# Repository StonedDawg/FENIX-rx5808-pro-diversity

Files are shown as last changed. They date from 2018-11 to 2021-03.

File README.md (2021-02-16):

https://discord.gg/gG2sjjK

Diversity receiver designed around an ESP32 and touchpad UI.

  *   15 kHz antenna switching rate e.g. once every NTSC video line.
  *   72 selectable frequencies
  *   Rapid spectrum analyser with selectable peaks.  See below for more details.
  *   Switch from diversity mode, to single antenna mode (A or B).

Menu demo (36 seconds) https://www.youtube.com/watch?v=VTEIN2PMyIs

Indoor flight (29 seconds) https://www.youtube.com/watch?v=gvrL2I_6KYo



**Calibration**

When first built and turned on you will be greeted with a calibration screen.  Set a VTx to 25 mW and on your favourite band/frequency (F4 for 5800 MHz) and place the VTx next to the goggles.  Tap the touchpad and the module will sweep all frequencies tracking maximum and minimum RSSI values.  When completed you will see the final min/max values for each receiver and can tapping again saves these values.
press any button to step the process.
The calibration process can be enhanced by selecting "enhance calibration" from menu or reset by selecting "factory reset" from internal settings menu.

**Diversity or single antenna selection**

Tapping on mode cycles through diversity, antenna A, and antenna B modes.

**button navigation**

use fatshark up/down CH as the button. changing value (going up or going down) will cycle
menu. to simulate enter button, change the direction, for example, after cycling with up button, to select the item, press the down button.

**note : due to fatshark "garbage" button system as Jye said, when button up or down has been pressed too many time (fatshark will do longer beep when pressed), menu cycling will stop. to keep cycling the menu, go with the opposite direction, it will not simulate enter button from a max-ed value button.

## BOM

  *   1 x PCB - Upload the Gerber.zip found in the PCB folder to jlcpcb.com, select 1mm thickness and your favourite colour. https://easyeda.com/jyesmith/esp32-fatshark-module-v3
  *   1 x GlidePoint circle pads Part Number (SPI) TM023023-2024-002
     *   https://www.cirque.com/glidepoint-circle-trackpads
     *   https://au.mouser.com/ProductDetail/Cirque/TM023023-2024-002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
  *   1 x TTGO Micro-32
     *   https://www.aliexpress.com/item/Ttgo-Micro-32-V2-0-Wifi-Wireless-Bluetooth-Module-Esp32-Pico-D4-Ipex-Esp-32/32982085061.html
  *   2 x RX5808.  The receiver linked below has given better results than the more commonly available receiver (the version without the 2 extra tabs).  The RSSI voltage range is  larger and the minimum RSSI is consistent across all frequencies.
     *   https://www.aliexpress.com/item/Swiftflying-Boscam-FPV-5-8G-Wireless-Audio-Video-Receiving-Module-For-RX5808/32841092602.html
  *   2 x Antenna Connectors
     *   https://www.aliexpress.com/item/5-pcs-RF-Coaxial-Long-SMA-Female-Straight-Edge-15mm-tooth-PCB-Connector-Adapter/32913905715.html
  *   3 x  Switch CD4065
  *   3.3V Regulator AMS1117-3.3
  *   2 x 10uF 0603 SMD Capacitors
  *   1 x 0.1uF 0603 SMD Capacitor
  *   1 x 10k 0603 SMD Resistors (EN pullup)
  *   2 x 100k 0603 SMD Resistors (RSSI pulldown)
  *   3 x 510 ohm 0603 SMD Resistors (LEDs) (Optional)
  *   3 x 0603 LEDs.  1 (red) for power and 2 (green) for indicating which antenna is selected (Optional)
  *   1 x boot button
  *   1 x 9 pin header
  *   2 x 4mm M2 standoffs and screws

# Wiring

https://easyeda.com/jyesmith/esp32-fatshark-module-v3

 

The touchpad works better with a cover.  I use a piece of electric tape.

 

 

 



## Flashing
initial flashing :
Tx and Rx pins to the TTGO are broken out to the upper 2 pins that plug into the goggles.  Connect these, along with GND (pin 3rd from bottom) and 5V (bottom pin), then flash using your favourite FTDI.

next update flashing can use OTA.

## Recognition

This code is a forked from [sheaivey/rx5808-pro-diversity](https://github.com/sheaivey/rx5808-pro-diversity).

## Code

The code is distributed under the [MIT license](LICENSE.md).

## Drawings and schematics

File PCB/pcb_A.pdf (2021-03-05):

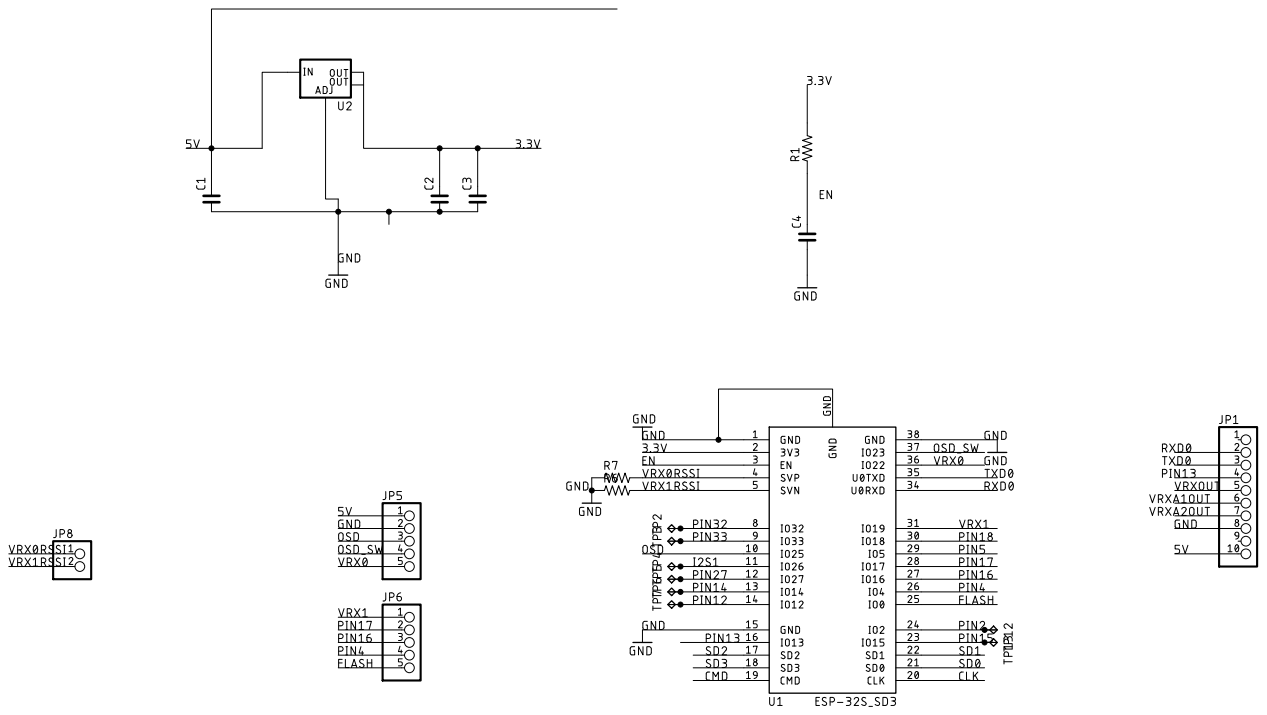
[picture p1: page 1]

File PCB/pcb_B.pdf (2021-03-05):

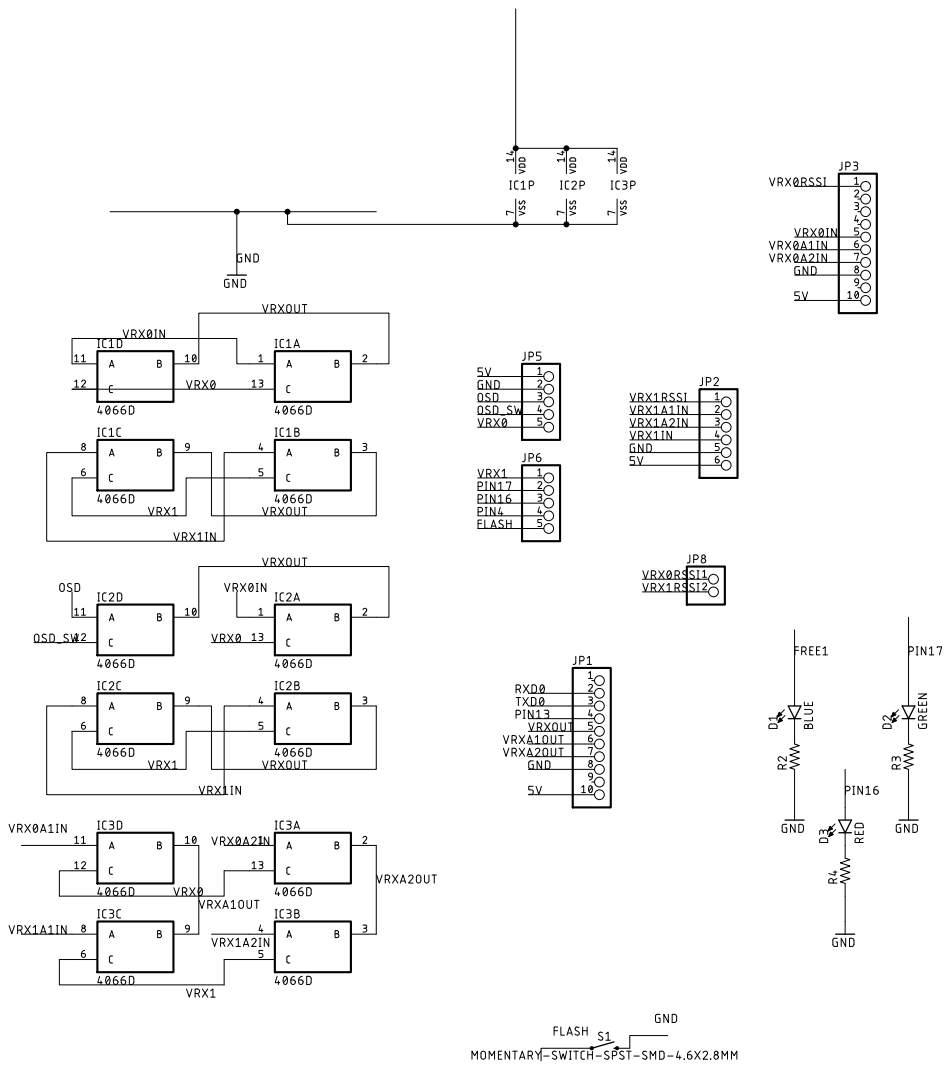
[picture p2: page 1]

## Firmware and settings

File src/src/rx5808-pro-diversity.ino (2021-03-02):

/*
   SPI driver based on fs_skyrf_58g-main.c Written by Simon Chambers
   TVOUT by Myles Metzel
   Scanner by Johan Hermen
   Inital 2 Button version by Peter (pete1990)
   Refactored and GUI reworked by Marko Hoepken
   Universal version my Marko Hoepken
   Diversity Receiver Mode and GUI improvements by Shea Ivey
   OLED Version by Shea Ivey
   Seperating display concerns by Shea Ivey

  The MIT License (MIT)

  Copyright (c) 2015 Marko Hoepken

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
  THE SOFTWARE IS PROVIDED "AS IS", WITHOUT WARRANTY OF ANY KIND, EXPRESS OR
  IMPLIED, INCLUDING BUT NOT LIMITED TO THE WARRANTIES OF MERCHANTABILITY,
  FITNESS FOR A PARTICULAR PURPOSE AND NONINFRINGEMENT. IN NO EVENT SHALL THE
  AUTHORS OR COPYRIGHT HOLDERS BE LIABLE FOR ANY CLAIM, DAMAGES OR OTHER
  LIABILITY, WHETHER IN AN ACTION OF CONTRACT, TORT OR OTHERWISE, ARISING FROM,
  OUT OF OR IN CONNECTION WITH THE SOFTWARE OR THE USE OR OTHER DEALINGS IN THE
  SOFTWARE.
*/

#include <EEPROM.h>
#include "esp_pm.h"
#include "settings.h"
#include "settings_eeprom.h"
#include "state_home.h"
#include "channels.h"
#include "receiver.h"
//#include "receiver_spi.h"
#include "state.h"
#include "ui.h"
#include "voltage.h"
#include "temperature.h"
//#include "touchpad.h"
//#include "receiver_spi.h"
#include <esp_now.h>
#include <WiFi.h>
#include "ExpressLRS_Protocol.h"
#include "WebUpdater.h"
#include "fsbutton.h"
#include "statusled.h"

#ifdef SPEED_TEST
    uint32_t n = 0; 
    uint32_t previousTime = millis();
#endif

fsBtn fatBtn;

//vrxDock vrxMdl;


/* 
    esp-now setup for communicating to https://github.com/AlessandroAU/ExpressLRS
    broadcastAddress is the mac of your receiving esp8266
*/


void floatUnusedPins(void);
uint8_t broadcastAddress[] = {0x50, 0x02, 0x91, 0xDA, 0x56, 0xCA,   // esp32 tx 50:02:91:DA:56:CA
                              0x50, 0x02, 0x91, 0xDA, 0x37, 0x84};  // r9 tx    50:02:91:DA:37:84
                              
bool updatingOTA = false;
uint32_t previousLEDTime = 0;
/**
vrxDockBtn vrxBtn0;
vrxDockBtn vrxBtn1;
vrxDockBtn vrxBtn2;
*/

void setup()
{
    rtc_clk_cpu_freq_set(RTC_CPU_FREQ_240M);
    esp_pm_lock_handle_t powerManagementLock;
    esp_pm_lock_create(ESP_PM_CPU_FREQ_MAX, 0, "compositeCorePerformanceLock", &powerManagementLock);
    esp_pm_lock_acquire(powerManagementLock);  
/**
vrxBtn0.residedAct = 0;
vrxBtn0.pressed = 0;
vrxBtn0.pin = PIN_BUTTON0;
vrxBtn0.lastReading = 0;
vrxBtn0.lastDebounceTime = 0;
vrxBtn0.changedTime = 0;
vrxBtn0.action0 = decrementVrxMode;
vrxBtn0.action1 = noActionBtn;
vrxBtn0.action2 = noActionBtn;

vrxBtn1.residedAct = 0;
vrxBtn1.pressed = 0;
vrxBtn1.pin = PIN_BUTTON1;
vrxBtn1.lastReading = 0;
vrxBtn1.lastDebounceTime = 0;
vrxBtn1.changedTime = 0;
vrxBtn1.action0 = noActionBtn;
vrxBtn1.action1 = noActionBtn;
vrxBtn1.action2 = enterOTA;

vrxBtn2.residedAct = 0;
vrxBtn2.pressed = 0;
vrxBtn2.pin = PIN_BUTTON2;
vrxBtn2.lastReading = 0;
vrxBtn2.lastDebounceTime = 0;
vrxBtn2.changedTime = 0;
vrxBtn2.action0 = incrementVrxMode;
vrxBtn2.action1 = noActionBtn;
vrxBtn2.action2 = noActionBtn;
*/


    //#ifdef SPEED_TEST
        //Serial.begin(115200);
    //#endif

    ////Serial.println("Setting Up..");
    EEPROM.begin(2048);
    
    ////Serial.println("EEPROM begin DONE");
    //SPI.begin();
    EepromSettings.setup();
    floatUnusedPins();
    statusLedInit();
    fsBtnInit();
    Receiver::setup(); 
    
    ////Serial.println("EEPROM set");
    
    
    
    ////Serial.println("pin set");
    StateMachine::setup();
    
    ////Serial.println("Statemachine set");
    Ui::setup(); 
    
    ////Serial.println("ui set");
    //TouchPad::setup(); 

    // Has to be last setup() otherwise channel may not be set.
    // RX possibly not booting quick enough if setup() is called earler.
    // delay() may be needed.
    
    ////Serial.println("Receiver set");
    if (!EepromSettings.isCalibrated) {
        
    ////Serial.println("not calibrated");
        StateMachine::switchState(StateMachine::State::SETTINGS_RSSI); 
        EepromSettings.initDefaults();
        Ui::tvOn();
        
    ////Serial.println("tv on");
    } else {
        StateMachine::switchState(StateMachine::State::HOME); 
        Ui::tvOn();
    ////Serial.println("go to home");
    }


    if (EepromSettings.otaUpdateRequested)
    {
        
    ////Serial.println("ota update requested");
        BeginWebUpdate();
        EepromSettings.otaUpdateRequested = false;
        EepromSettings.save();
        updatingOTA = true;
    } 
    
    /**else
     
        esp-now setup for communicating to https://github.com/AlessandroAU/ExpressLRS
    
    {
        
    ////Serial.println("no OTA req, continue..");
        WiFi.mode(WIFI_STA);

        if (esp_now_init() != ESP_OK) {
            ////Serial.println("Error initializing ESP-NOW");
            return;
        }

        // Adds broadcastAddress
        ////Serial.println("broadcasting address");
        esp_now_peer_info_t injectorInfo;
        for (int i = 0; i < sizeof(broadcastAddress) / 6; i++)
        {
            memcpy(injectorInfo.peer_addr, broadcastAddress + (6 * i), 6);
            injectorInfo.channel = 0;  
            injectorInfo.encrypt = false;

            if (esp_now_add_peer(&injectorInfo) != ESP_OK){
                ////Serial.println("Failed to add peer");
                return;
            }
        }
    }
    */
    ////Serial.println("Done setup");  
}

void floatUnusedPins() {

    // Rx and Tx set as input so that they are high impedance when conencted to goggles.
    //pinMode(PIN_BUTTON0, INPUT_PULLUP);
    //pinMode(PIN_BUTTON1, INPUT_PULLUP);
    //pinMode(PIN_BUTTON2, INPUT_PULLUP);
    
    //pinMode(PIN_SPI_SLAVE_SELECT_RX_A, OUTPUT);
    //digitalWrite(PIN_SPI_SLAVE_SELECT_RX_A, HIGH);
    
    //pinMode(PIN_SPI_SLAVE_SELECT_RX_B, OUTPUT);
    //digitalWrite(PIN_SPI_SLAVE_SELECT_RX_B, HIGH);
    /**
    pinMode(PIN_TOUCHPAD_SLAVE_SELECT, OUTPUT);
    digitalWrite(PIN_TOUCHPAD_SLAVE_SELECT, HIGH);
    pinMode(PIN_TOUCHPAD_DATA_READY, INPUT);
    */

    
    pinMode(UNUSED_PIN0,INPUT);
    gpio_pulldown_dis(UNUSED_GPIO_PIN0);
    gpio_pullup_dis(UNUSED_GPIO_PIN0);
    gpio_set_pull_mode(UNUSED_GPIO_PIN0,GPIO_FLOATING);
    
    pinMode(UNUSED_PIN1,INPUT);
    gpio_pulldown_dis(UNUSED_GPIO_PIN1);
    gpio_pullup_dis(UNUSED_GPIO_PIN1);
    gpio_set_pull_mode(UNUSED_GPIO_PIN1,GPIO_FLOATING);
    
    pinMode(UNUSED_PIN2,INPUT);
    gpio_pulldown_dis(UNUSED_GPIO_PIN2);
    gpio_pullup_dis(UNUSED_GPIO_PIN2);
    gpio_set_pull_mode(UNUSED_GPIO_PIN2,GPIO_FLOATING);
    
    pinMode(UNUSED_PIN3,INPUT);
    gpio_pulldown_dis(UNUSED_GPIO_PIN3);
    gpio_pullup_dis(UNUSED_GPIO_PIN3);
    gpio_set_pull_mode(UNUSED_GPIO_PIN3,GPIO_FLOATING);
    
    pinMode(UNUSED_PIN4,INPUT);
    gpio_pulldown_dis(UNUSED_GPIO_PIN4);
    gpio_pullup_dis(UNUSED_GPIO_PIN4);
    gpio_set_pull_mode(UNUSED_GPIO_PIN4,GPIO_FLOATING);


}

void loop() {

    if (updatingOTA)
    {
        HandleWebUpdate();
        if (millis() > previousLEDTime+100)
        {
            //digitalWrite(PIN_VRX_SWITCH0, !digitalRead(PIN_VRX_SWITCH0));
            previousLEDTime = millis();
        }
    } else
    {
        
        ////Serial.println("updating receiver");
        Receiver::update();
        
        ////Serial.println("updating led");
        updateVrxLed(millis());
        
        ////Serial.println("updatingBtn");
        updateFSBtn();
        //TouchPad::update();

        if (Ui::isTvOn) {

        #ifdef USE_VOLTAGE_MONITORING  
            Voltage::update();
        #endif
            ////Serial.println("tv is on");
            Ui::display.begin(0);
            ////Serial.println("display began");
            StateMachine::update();
            ////Serial.println("statemachine updated");
            Ui::update();
            ////Serial.println("ui updated");
            Ui::display.end();
            ////Serial.println("display ended");
    
            EepromSettings.update();
            ////Serial.println("eeprom updated");
        } else {
            digitalWrite(OSD_SWITCH, LOW);
            }
        /**
        if (TouchPad::touchData.isActive) {
            Ui::UiTimeOut.reset();
        }
        */
        if (Ui::isTvOn &&
            Ui::UiTimeOut.hasTicked() &&
            StateMachine::currentState == StateMachine::State::HOME ) 
        {
            //Serial.println("osd timeout");
            Ui::tvOff();  
            EepromSettings.update();
            
        }
        
        if (!Ui::isTvOn &&
            (getFSBtnFlags()))
        {
            clearFSBtnFlags();
            //StateMachine::switchState(StateMachine::State::HOME); 
            Ui::tvOn();
            Ui::UiTimeOut.reset();

            //Serial.println("wake osd");
        }
        
        //TouchPad::clearTouchData();  
        

        #ifdef SPEED_TEST
            n++;
            uint32_t nowTime = millis();
            if (nowTime > previousTime + 1000) {
                ////Serial.print(n);
                ////Serial.println(" Hz");
                previousTime = nowTime;
                n = 0;
            }
        #endif
    }
}

uint8_t crc8_dvb_s2(uint8_t crc, unsigned char a)
{
    crc ^= a;
    for (int ii = 0; ii < 8; ++ii) {
        if (crc & 0x80) {
            crc = (crc << 1) ^ 0xD5;
        } else {
            crc = crc << 1;
        }
    }
    return crc;
}

void sendToExLRS(uint16_t function, uint16_t payloadSize, const uint8_t *payload)
{
    uint8_t nowDataOutput[9 + payloadSize] = {0};
    
    nowDataOutput[0] = '$';
    nowDataOutput[1] = 'X';
    nowDataOutput[2] = '<';
    nowDataOutput[3] = '0';
    nowDataOutput[4] = function & 0xff;
    nowDataOutput[5] = (function >> 8) & 0xff;
    nowDataOutput[6] = payloadSize & 0xff;
    nowDataOutput[7] = (payloadSize >> 8) & 0xff;

    for (int i = 0; i < payloadSize; i++)
    {
        nowDataOutput[8 + i] = payload[i];
    }

    uint8_t ck2 = 0;
    for(int i = 3; i < payloadSize+8; i++)
    {
        ck2=crc8_dvb_s2(ck2, nowDataOutput[i]);
    }
    nowDataOutput[payloadSize+8] = ck2;

    for (int i = 0; i < sizeof(broadcastAddress) / 6; i++)
    {
        uint8_t tempBroadcastAddress[6];
        memcpy(tempBroadcastAddress, broadcastAddress + (6 * i), 6);
        esp_now_send(tempBroadcastAddress, (uint8_t *) &nowDataOutput, sizeof(nowDataOutput));
    }
}

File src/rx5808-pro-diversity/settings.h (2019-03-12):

/*
 * Setings file by Shea Ivey

The MIT License (MIT)

Copyright (c) 2015 Shea Ivey

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
THE SOFTWARE IS PROVIDED "AS IS", WITHOUT WARRANTY OF ANY KIND, EXPRESS OR
IMPLIED, INCLUDING BUT NOT LIMITED TO THE WARRANTIES OF MERCHANTABILITY,
FITNESS FOR A PARTICULAR PURPOSE AND NONINFRINGEMENT. IN NO EVENT SHALL THE
AUTHORS OR COPYRIGHT HOLDERS BE LIABLE FOR ANY CLAIM, DAMAGES OR OTHER
LIABILITY, WHETHER IN AN ACTION OF CONTRACT, TORT OR OTHERWISE, ARISING FROM,
OUT OF OR IN CONNECTION WITH THE SOFTWARE OR THE USE OR OTHER DEALINGS IN THE
SOFTWARE.
*/

#ifndef SETTINGS_H
#define SETTINGS_H

// === Module ==================================================================
//
// You can choose one module only
//
// =============================================================================

#define FENIX_QUADVERSITY
//#define REALACC_RX5808_PRO_PLUS_OSD

// === EEPROM ==================================================================
//
// Select ROM used. Option included for testing.
//
// =============================================================================

//#define EEPROM_AT24C02 // WORKING
//#define EEPROM_AT24C16 // WORKING
//#define EEPROM_AT24C32 // NOT TESTED
#define EEPROM_AT24C64 // WORKING

// === Display Module ==========================================================
//
// You can choose one display module only. Only 128x64 OLED displays are
// supported.
//
// =============================================================================

//#define DISABLE_OLED

//#define OLED_128x64_ADAFRUIT_SCREENS
#define TVOUT_SCREENS

// Enable this if your screen is upside down.
//#define USE_FLIP_SCREEN

#define OLED_ADDRESS 0x3C // I2C address for display (0x3C or 0x3D, usually)

// === Receiver Module =========================================================
//
// Select which receiever you are using. Required for time tuning.
//
// =============================================================================

#define RX5808
//#define RX5880

// Can enable this to powerdown the audio blocks on the RX58xx if you don't
// need it. Save a tiny bit of power, make your videos less noisy.
//
// WARNING: Makes RSSI act a little weird.
//#define DISABLE_AUDIO

// === Features ===============================================================

// You can use any of the arduino analog pins to measure the voltage of the
// battery. See additional configuration below.
//#ifdef FENIX_QUADVERSITY
//    #define USE_VOLTAGE_MONITORING
//#endif

// === Pins ====================================================================

#ifdef FENIX_QUADVERSITY

//    #define PIN_BUTTON_UP_PRESSED PA12 // 33
//    #define PIN_BUTTON_MODE_PRESSED PA15 // 38
//    #define PIN_BUTTON_DOWN_PRESSED PA8 // 29
//    #define PIN_BUTTON_RIGHT_PRESSED PA11 // 32
//    #define PIN_BUTTON_LEFT_PRESSED PB15 // 28

    #define PIN_TOUCHPAD_DATA_READY PA12 // 33
   
    
//    #define PIN_BUTTON_FATSHARK_EB0 PB3 // 39
//    #define PIN_BUTTON_FATSHARK_EB1 PB4  // 40
//    #define PIN_BUTTON_FATSHARK_EB2 PB5  // 41
    
    #define PIN_LED PB8 // 45
    #define PIN_BUZZER PB9 // 46 // Must be an active buzzer, not passive.
    #define PIN_OSDCONTROL PC15 // 4
    
    #define PIN_SPI_DATA PB12          // 25 // CH1
    #define PIN_SPI_SLAVE_SELECT PB13  // 26 // CH2
    #define PIN_SPI_CLOCK PB14         // 27 // CH3
    
    #define PIN_RSSI_A PA3 // 13
    #define PIN_LED_A PB1 // 19
    #define PIN_RSSI_B PA2 // 12
    #define PIN_LED_B PB0 // 18
    #define PIN_RSSI_C PA6 // 16
    #define PIN_LED_C PC14 // 3
    #define PIN_RSSI_D PA4 // 15
    #define PIN_LED_D PC13 // 2
    
    #define PIN_VBAT PA0 // 10
    
    //OLED_SCL PB6
    //OLED_SDA PB7
    //
    // This pins are fixed in the library and Im unsure how to change them.
    //TVout PA1 
    //TVout PA7
#endif

// === Pins ====================================================================
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

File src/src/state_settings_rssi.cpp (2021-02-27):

#include <stdint.h>

#include "state_settings_rssi.h"

#include "receiver.h"
#include "channels.h"

#include "settings.h"
#include "settings_eeprom.h"

#include "ui.h"
#include "fsbutton.h"
//#include "touchpad.h"

/**
extern vrxDockBtn vrxBtn0;
extern vrxDockBtn vrxBtn1;
extern vrxDockBtn vrxBtn2;
*/
extern fsBtn fatBtn;
void StateMachine::SettingsRssiStateHandler::onEnter() {
    internalState = InternalState::WAIT_FOR_LOW;
    
}

void StateMachine::SettingsRssiStateHandler::onUpdate() {

    onUpdateDraw();
    
    if (getFSBtnFlags() && internalState!=InternalState::SCANNING_LOW) {
      clearFSBtnFlags();
      doTapAction();
    }
  
    if (!Receiver::isRssiStable() || !Receiver::hasRssiUpdated)
        return;

    for (int i = 0; i < 100; i++) {
        Receiver::rssiARaw = 0.9 * Receiver::rssiARaw + 0.1 * analogRead(PIN_RSSI_A);
        Receiver::rssiBRaw = 0.9 * Receiver::rssiBRaw + 0.1 * analogRead(PIN_RSSI_B);
    }

    switch (internalState) {
        case InternalState::SCANNING_LOW:
        
            if ( Channels::getFrequency(Receiver::activeChannel) >= 5658) { // Only use min max above R1 to stay within RX5808 freq range
                
                if (Receiver::rssiARaw < EepromSettings.rssiAMin)
                    EepromSettings.rssiAMin = Receiver::rssiARaw;
    
                if (Receiver::rssiARaw > EepromSettings.rssiAMax) {
                    EepromSettings.rssiAMax = Receiver::rssiARaw;
                    bestChannel = Receiver::activeChannel;
                }
                if (Receiver::rssiBRaw < EepromSettings.rssiBMin)
                    EepromSettings.rssiBMin = Receiver::rssiBRaw;
                    
                if (Receiver::rssiBRaw > EepromSettings.rssiBMax)
                    EepromSettings.rssiBMax = Receiver::rssiBRaw;
                #ifdef QUADVERSITY
                if (EepromSettings.quadversity) {
                    if (Receiver::rssiCRaw < EepromSettings.rssiCMin)
                        EepromSettings.rssiCMin = Receiver::rssiCRaw;
                    if (Receiver::rssiCRaw > EepromSettings.rssiCMax)
                        EepromSettings.rssiCMax = Receiver::rssiCRaw;
                        
                    if (Receiver::rssiDRaw < EepromSettings.rssiDMin)
                        EepromSettings.rssiDMin = Receiver::rssiDRaw;
                    if (Receiver::rssiDRaw > EepromSettings.rssiDMax)
                        EepromSettings.rssiDMax = Receiver::rssiDRaw;
                }
                #endif
                
            }
        break;
    }
    
    if(getFSBtnFlags() && sweepWaitBtn){
        sweepWaitBtn = 0;
        clearFSBtnFlags();
    }
    
    if(sweepWaitBtn == 0){
        Receiver::setChannel((Receiver::activeChannel + 1) % CHANNELS_SIZE);
        sweepWaitBtn = 1;
    }

    if (internalState==InternalState::SCANNING_LOW || internalState==InternalState::SCANNING_HIGH) {

        Ui::display.setTextColor(100);
        Ui::display.setCursor( 100, 80);
        Ui::display.printLarge(Channels::getName(Receiver::activeChannel), 6, 6);

        uint8_t progressBar = (SCREEN_WIDTH-100-2) * (currentSweep * CHANNELS_SIZE + Receiver::activeChannel) / (RSSI_SETUP_RUN * CHANNELS_SIZE);
        Ui::display.fillRect(52, 152, progressBar, 20, 100);
  
    }
          
    if (Receiver::activeChannel == 0) {
        currentSweep++;

        if (currentSweep >= RSSI_SETUP_RUN && internalState == InternalState::SCANNING_LOW) {
            internalState = InternalState::DONE;
            sweepWaitBtn = 0;
        }
    }

}

void StateMachine::SettingsRssiStateHandler::doTapAction() {
        
    switch (internalState) {
        case InternalState::WAIT_FOR_LOW:
            internalState = InternalState::SCANNING_LOW;
            currentSweep = 0;
            sweepWaitBtn = 0;
            Receiver::setChannel(0);
            bestChannel = 0;
    /**
            EepromSettings.rssiAMin = UINT16_MAX;
            EepromSettings.rssiAMax = 0;
            EepromSettings.rssiBMin = UINT16_MAX;
            EepromSettings.rssiBMax = 0;
            EepromSettings.rssiCMin = UINT16_MAX;
            EepromSettings.rssiCMax = 0;
            EepromSettings.rssiDMin = UINT16_MAX;
            EepromSettings.rssiDMax = 0;
    */        
            ////Serial.println("ok to scan");
        break;

        case InternalState::DONE:
        
            ////Serial.println("scan done");
            
            EepromSettings.isCalibrated = true;
            
            EepromSettings.save();

            Receiver::setChannel(
              Channels::getClosestChannel(
                Channels::getCenterFreq(
                  Channels::getFrequency(bestChannel))));
            
            EepromSettings.lastKnownMenuItem = 0;
            EepromSettings.markDirty();
            //internalState = InternalState::IDLE;
            StateMachine::switchState(StateMachine::State::HOME);
            
            
        break;
    }

}


void StateMachine::SettingsRssiStateHandler::onInitialDraw() {
//    Ui::needUpdate(); // Lazy. :(
    onUpdateDraw(); // Lazier. :(
}
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

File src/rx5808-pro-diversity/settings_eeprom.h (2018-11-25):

#ifndef SETTINGS_EEPROM_H
#define SETTINGS_EEPROM_H


#include <stdint.h>
#include <avr/pgmspace.h>

#include "settings.h"
#include "settings_internal.h"
#include "receiver.h"
#include "state.h"


struct EepromSettings {
    uint8_t versionNumber;
    
    uint8_t isCalibrated;
    
    uint8_t startChannel;
    int lastKnownMenuItem;
    StateMachine::State lastKnownState;

    uint8_t beepEnabled;

    uint8_t searchManual;
    uint8_t searchOrderByChannel;
    
    uint16_t rssiAMin;
    uint16_t rssiAMax;
    uint16_t rssiBMin;
    uint16_t rssiBMax;
    uint16_t rssiCMin;
    uint16_t rssiCMax;
    uint16_t rssiDMin;
    uint16_t rssiDMax;

    uint8_t vbatScale;
    uint8_t vbatWarning;
    uint8_t vbatCritical;
    
    uint8_t favouriteChannels[8];
    int spectatorChannels[8];

    uint8_t quadversity;
    uint8_t saveScreenOn;
    uint8_t useOledScreen;
    uint8_t useFastBoot;
    uint8_t selectedHomePage;
    uint8_t buttonBeep;
    uint8_t invertDisplay;
    uint8_t rotateOled;

    // Internal settings
    uint8_t spectatorFreqScanStep;
    uint8_t spectatorFWHM;
    uint8_t rssiSeekTreshold;
    uint16_t rssiMinTuneTime;
    uint8_t rssiHysteresis;
    uint16_t rssiHysteresisPeriod;

    #ifndef EEPROM_AT24C02
       unsigned char customLogo[128*64/8];
    #endif
    
    void update();

    void load();
    void save();
    void markDirty();

    void initDefaults();
};


PROGMEM const struct {
    uint8_t versionNumber = VERSION_NUMBER;
    
    uint8_t isCalibrated = false;
    
    uint8_t startChannel = 0;
    int lastKnownMenuItem = 0;
    StateMachine::State lastKnownState = StateMachine::State::HOME;

    uint8_t beepEnabled = true;

    uint8_t searchManual = false;
    uint8_t searchOrderByChannel = false;
    
    uint16_t rssiAMin = RSSI_MIN_VAL;
    uint16_t rssiAMax = RSSI_MAX_VAL;
    uint16_t rssiBMin = RSSI_MIN_VAL;
    uint16_t rssiBMax = RSSI_MAX_VAL;
    uint16_t rssiCMin = RSSI_MIN_VAL;
    uint16_t rssiCMax = RSSI_MAX_VAL;
    uint16_t rssiDMin = RSSI_MIN_VAL;
    uint16_t rssiDMax = RSSI_MAX_VAL;

    uint8_t vbatScale = VBAT_SCALE;
    uint8_t vbatWarning = WARNING_VOLTAGE;
    uint8_t vbatCritical = CRITICAL_VOLTAGE;
    
    uint8_t favouriteChannels[8] = {32, 33, 34, 35, 36, 37, 38, 39}; // Race band
    int spectatorChannels[8] = {-1, -1, -1, -1, -1, -1, -1, -1};
    
    uint8_t quadversity = false;
    uint8_t saveScreenOn = 1;
    uint8_t useOledScreen = false;
    uint8_t useFastBoot = true;
    uint8_t selectedHomePage = 0;
    uint8_t buttonBeep = true;
    uint8_t invertDisplay = false;
    uint8_t rotateOled = false;

    // Internal settings
    uint8_t spectatorFreqScanStep = 5;
    uint8_t spectatorFWHM = 20;
    uint8_t rssiSeekTreshold = 50;
    uint16_t rssiMinTuneTime = 30;
    uint8_t rssiHysteresis = 0;
    uint16_t rssiHysteresisPeriod = 0;

    #ifndef EEPROM_AT24C02
        unsigned char customLogo[128*64/8] = {0};
    #endif
} EepromDefaults;


extern EepromSettings EepromSettings;


#endif

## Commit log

2018-11-25 fix(touchpad) change to use DR pin
    Minimise noise in menu UI by not continually reading the register to check for touch data.
    [rx5808-pro-diversity.ino, settings.h, touchpad.cpp]
2019-03-12 fix(touch) adds touchpad define for testing
    reverses touchpad commands which help when using an external monitor
    [settings.h, touchpad.cpp]
2019-03-21 refact(voltage) remove vbat alarm and temp
2021-02-05 remove timertap
2021-02-06 init led
2021-02-14 add debug print
2021-02-14 fix flipped output and input pullup
    [rx5808-pro-diversity.ino]
2021-02-15 use fatshark button
2021-02-15 fix button define
2021-02-15 fix fsbutton and enable menu,wifi
    [fsbutton.cpp, rx5808-pro-diversity.ino]
2021-02-15 video select switched
2021-02-16 calibration is to enhance not reset
2021-02-16 fix enhance calibrate
2021-02-17 setup for V2 PCB
2021-02-26 pin setup
2021-02-26 make diversity switch work right away
2021-02-27 fix enhance calibration
2021-02-27 fix rssi min max init val
    [settings_eeprom.h]
2021-02-28 load default val if not calibrated yet
2021-03-02 float unused pin
2021-03-02 seperate pin setups
2021-03-05 ADD PCB
    [copper_bottom.gbr, copper_top.gbr, drills.xln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]
